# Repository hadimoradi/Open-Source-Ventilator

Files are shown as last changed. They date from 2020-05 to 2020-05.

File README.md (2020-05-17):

# Automated Ambubag
Auto Ambubag is a device to provide the minimum requirement for the patient in the critical situation facing COVID-19.

Auto Ambubag is suitable for various sizes of  Ambu bag. It scans the scale at the start time.

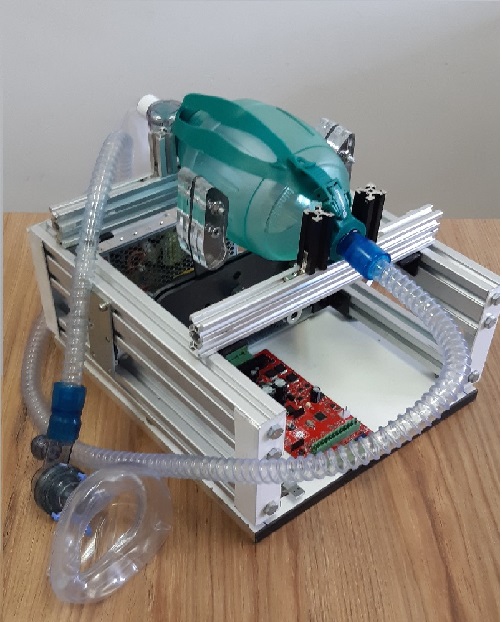
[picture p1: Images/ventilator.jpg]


### Breathing Parameters 
- #### Respiration Rate: 
     8-30 Respiration per minute 
- #### Tidal Volume:
  200-1000 cc per Ambu pumped
- #### I/E Rate(Inhale/Exhale Rate):
  1:1 , 1:2 , 1:3 , 1:4
- #### T hold:
  Ambu compressing time 

### Electrical Details
- voltage: 220 AC
- power: 200 W 

### Dimnetions 

32 * 36 *30 cm

10 kg

### TODO List
-  backup battery 
- measuring pick pressure, plateau,PEEP
- external oxygen cylinder

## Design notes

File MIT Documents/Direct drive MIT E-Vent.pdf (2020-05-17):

3/28/20 6:40 PM | 1

Gearmotor & “Windshield wiper” motors as direct drive units for MIT-E Vent: “TwinDrive” March 28, 2020, updated 3/30/2020
Prof. Alex Slocum, slocum@mit.edu
https://e-vent.mit.edu/

Background

On March 12, 2020 I started the quest for design, build, test an emergency breathing assist device in response to the critical shortage of ventilators the COVID-19 pandemic has created. My lab members volunteered to help and we formed the MIT-E Vent team (https://e-vent.mit.edu/ where we post information to share with the world) and we learned rapidly and made a lot of progress. Hindsight is often 2020, and this being 2020. The full story is part of another document… the purpose of this document is to describe how a geared mechanism led to a direct drive mechanism.

In general, rotary motion is preferred over sliding because it is more robust for millions of cycles in an environment that cannot be relied upon to carefully maintain the unit. Hence two hands pivoting together to squeeze an “Ambu bag” is a natural design to pursue. The force required on a pivoting “hand” at the Ambu bag center is about 100N to generate 50 cm H2O pressure. The distance from the pivot to center axis of a 125 mm (5 inch) diameter bag to get good “squeeze” is about 125-150mm. The speed of the bag center for compression to meet inspiration is thus about 176 mm/sec (7 in/s). FIRST robotics uses gearmotors with integral encoders and indeed an AndyMark PG71 motor we had on-hand proved to be very useful to develop the design concept of using a single motor to drive two pivoting hands geared together. However, millions of units worldwide will be needed, and in the search for a strong gearmotor to pivot the two hands geared together, it was suggested by many people contacted for their thoughts on the design to make it work with windshield wiper motors: Indeed a former student and business partner on ventures past, Dave Gessel who lives in Iraq, emailed me “There aren't any new "parts" here other than spares for things like cars or maybe washing machines. Car seat or windshield wiper motors, smart phone control, fabrication with hand tools OR import complete.” But windshield wiper motors typically have 10-15 N-m of stall torque, not enough to power two hands…

Meanwhile, a whole series of emails between the MIT E-Vent team and Toyota indicated that their wiper motors could match the specs of the AndyMark gearmotors, and an encoder could then be attached to one of the shafts that holds the hands. I had been discussing different drive methods for “paddle hands” with Richard Moore from Ford who was pursuing a system actuated by a geartrain powered by a standard motor Ford uses in its products. Richard was kind enough to check on windshield wiper gearmotor information (we still need to know what the allowable side load is on the output shaft)…

In addition, a few days ago my friend (and alum form my lab at MIT) Dr. Matthew Van Doren, who I had asked to help with stepper motor control for the TopDrive system created in concert Marcel Botha from NewLab.com. Steve Cohen and Marcel started NewLab as a way to help start a design and manufacturing renascence in NYC. Marcel and his amazing team of design people in New York in a matter of only a day took my early solid model for a “Top Drive” and evolved, built, and delivered test units for controls development.

Matt was working on the controls for the TopDrive unit provided to him by NewLab, and it got him thinking that modular robotic actuators (HDT A24 Actuator) that his brother’s robotics firm developed could directly power the fingers (or hands) that squeeze the Ambu bag. Matt took the shape of the rolling contact hands from the TopDrive and created a direct drive image or a very simple and modular system core:

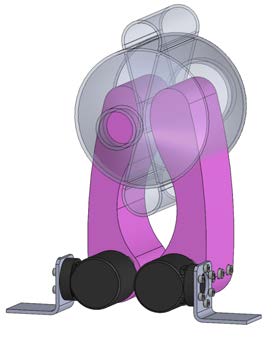
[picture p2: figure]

The HDT actuators are self-contained with controller, encoder…. really nice units. Perhaps more expensive than a couple of windshield wiper motors on a bracket with a simple control system, but hundreds a month can be in production right away, and they are a proven hardened and high-performance product, and HDT is an approved FDA manufacturer of such hardware.

Shortly thereafter, Richard Moore sent me this image of a Ford windshield wiper motor spec sheet, which is 2-3x stronger than what I have been used to in earlier hobby projects, and the higher torques now available inspired me to think fresh:

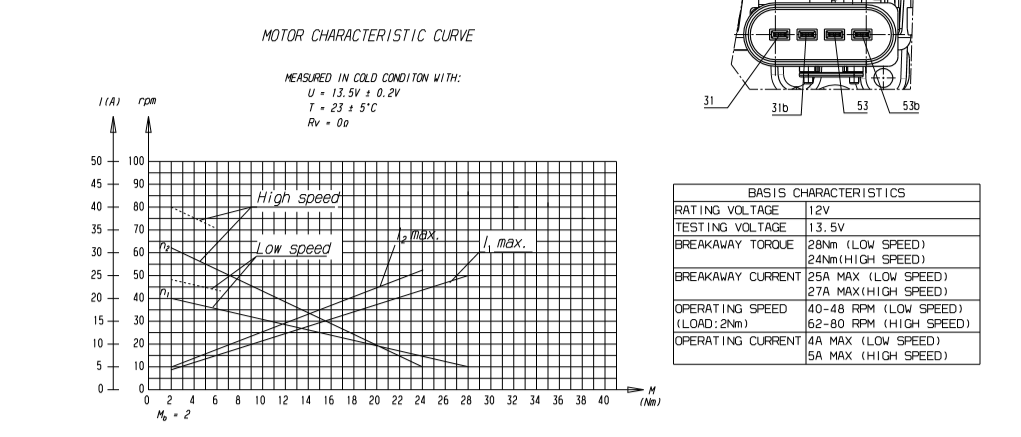
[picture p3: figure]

Déjà vu? Below is the image from my book FUNdaMENTALS of design that I wrote for course 2.007 where 25 years ago we were providing students big windshield wiper motors (note image in upper right of page) to use in their kits which had been donated by Ford! I still have a drawer of them in my basement:

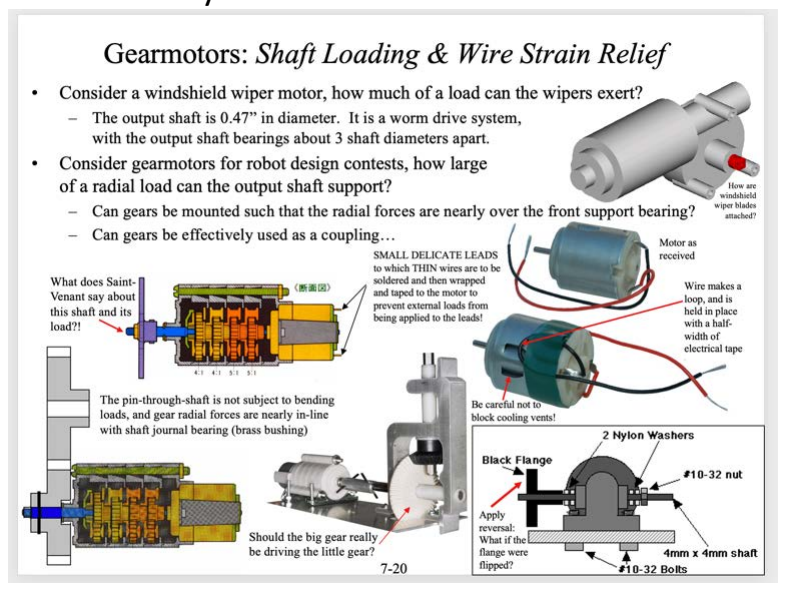
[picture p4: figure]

I had to put all this together, so I took a dog walk Saturday afternoon through our 100 acre woods, thinking about all the calculations I had been doing in spreadsheets for the geared hand
designs, and the dimensions and forces | POW it hit me while doing a first order analysis on
the trail…. The windshield wiper motors themselves might along work as a direct drive actuator. I came home and sketched the idea and then went to work modifying y design spreadsheet for the geared hands design while Solid Modeling the concept driven by the primary functional requirements of “hands” attached directly to output shaft of gearmotors (minimize complexity), minimize rubbing of the bag and motion of bag centerline while achieving a tidal volume flow of > 800 cm^3, and of course safety and fail safe operation ability.

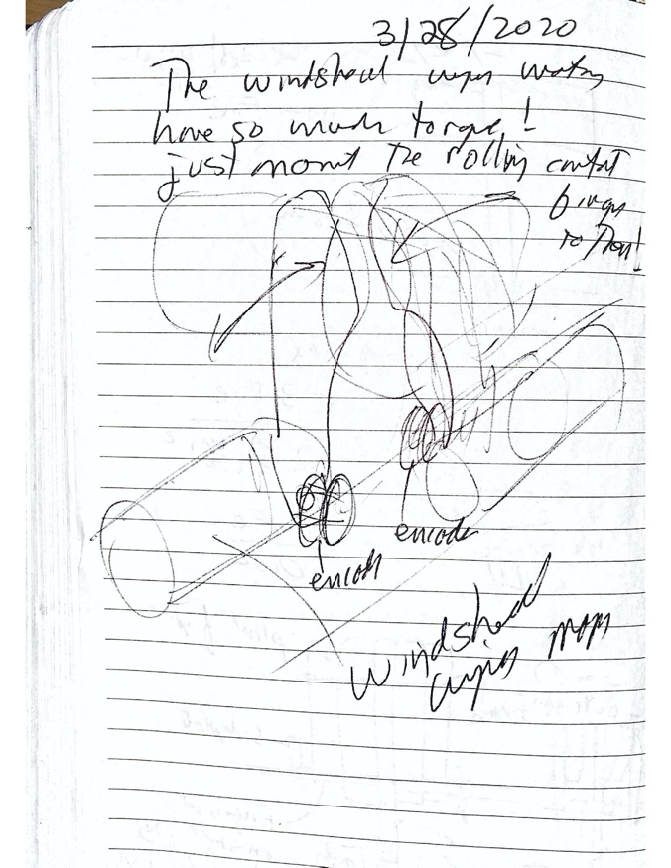
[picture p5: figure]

Had someone suggested this before in the past few days? I do not recall as these past days has been such a whirlwind as every day we hear how things are getting worse… so many lives at stake…. Thus, the thought was we could attach an “arm” to a windshield wiper motor output shaft, where the arm has “fingers” on each side like the MIT-E Vent unit we developed to create a wide “hand” to hold and compress the bag:

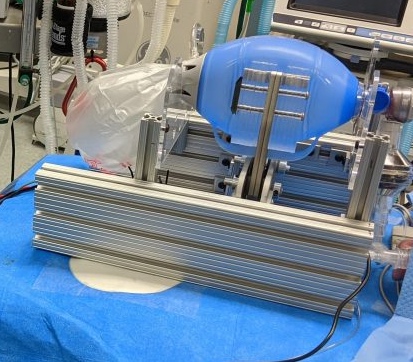
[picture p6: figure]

The key is the shape that squeezes the bag nicely as these early images from development of the TopDrive design report of 3/21/2020 show:

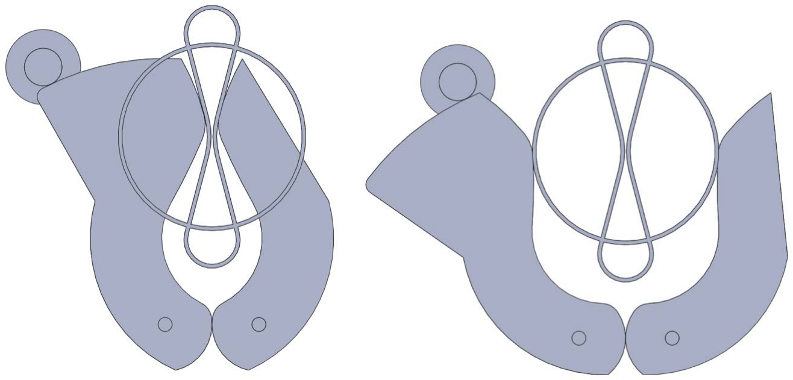
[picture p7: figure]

More than just effective rolling contact, then hands need to press on a wide surface region of the bag from both sides to get the “two hands” volme potential of the bag (>800 cc’s tidal volume of air).

“TwinDrive” concept

The key to direct drive the hands that squeeze the bag is a gearmotor to whose output shaft can be directly affixed an ”arm” with a “hand” that pushes on the bag. To minimize the torque required is to reduce the distance from the center of the bag to the rotation axis; however, the further away the hand is from the gearmotor axis of rotation, the more linear and uniform the motion of bag squeezing. The challenege then is to create a “cam-like” shape that is nice to the bag (minimize rubbing and motion of bag centerline). The original design was evolved with a few long contemplative walks through the woods to yield a reduction from the original 5.5” to 4.5” which results in 18% reduction in torque. The profile was also evovled to squeeze more of the bag giving more potential tidal volume:

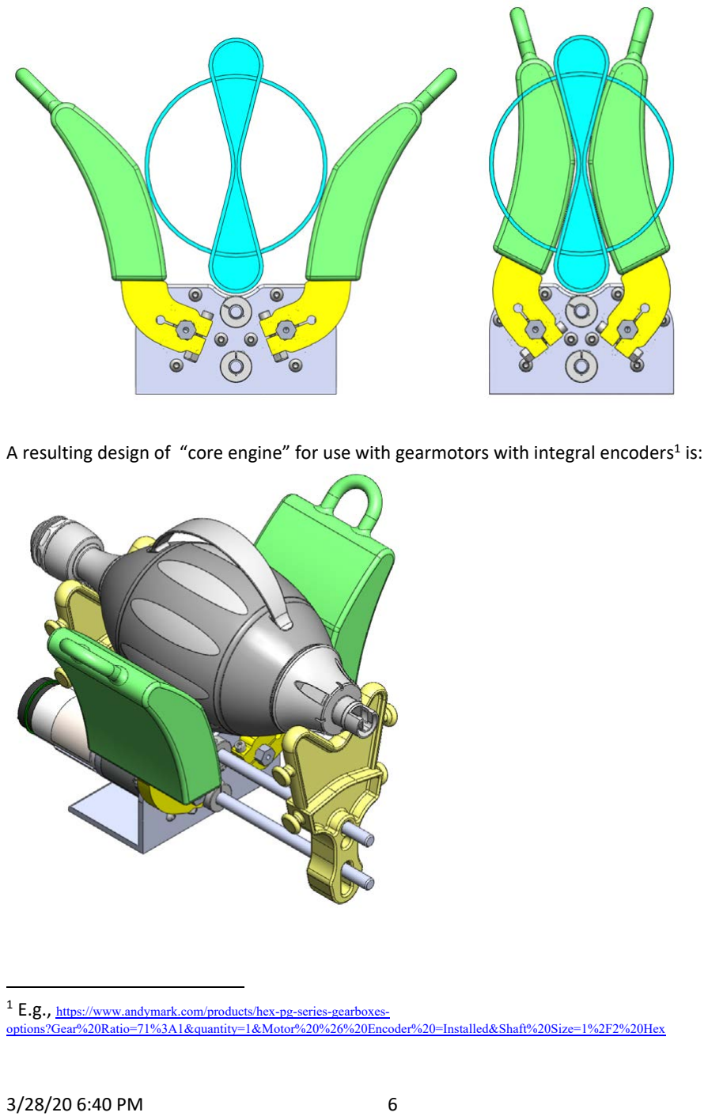
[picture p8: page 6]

A resulting design of “core engine” for use with gearmotors with integral encoders¹ is:

1 E.g., https://www.andymark.com/products/hex-pg-series-gearboxes-options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

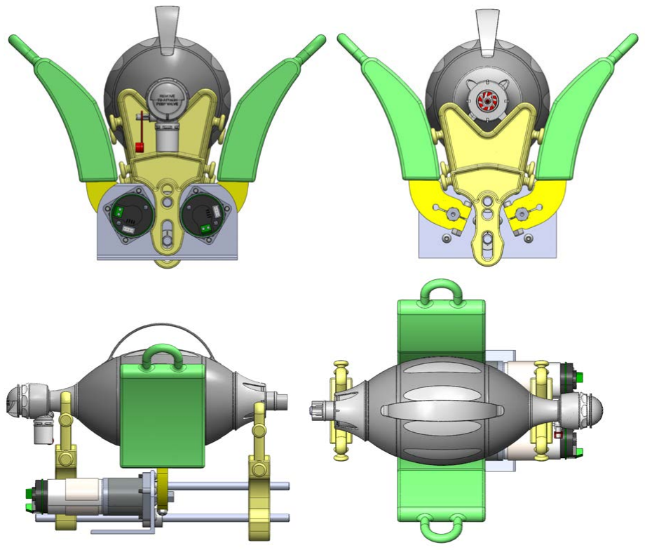
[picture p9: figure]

One can envision how the core design can be easily adpated for use with diffferent gearmotors or windshield wiper motors which can be mounted on opposing faces of a deep channel.

Position Sensing

Gearmotors with encoders provide very good feedback, but they will still need a home position flag. Windshield wiper motors generaly do not have inetrgal position sensors, but if they did (for dorect drive of wier blades) that would be a huge binus.

Else it would be very straightforward to on the arm have an arc shape on the bottom surface with fine “teeth” that an inductive sensor “count” (two can be used to yield quadrature effect)…. The design concept is very straightforward and the accompanying design spreadsheet can help bright engineers and makers all over the world rapidly design and make breating assist devices, whch are cntrolled by systems created by their electrical engineering counterparts, all working othegtehr with medical doctors to help people.

Fail-Safe Design

Some gearmotors with very high ratios or with wormgears are not backdriveable, as is common with many windshield wiper motors. This presents a hazerd of the bag is squeezed and the motor fails, because a clinician could not simply pry open the hands and pull the bag out. The answer is to pull the bag and hands out: this is made possible by creating a smooth curve over which printed hands slide:

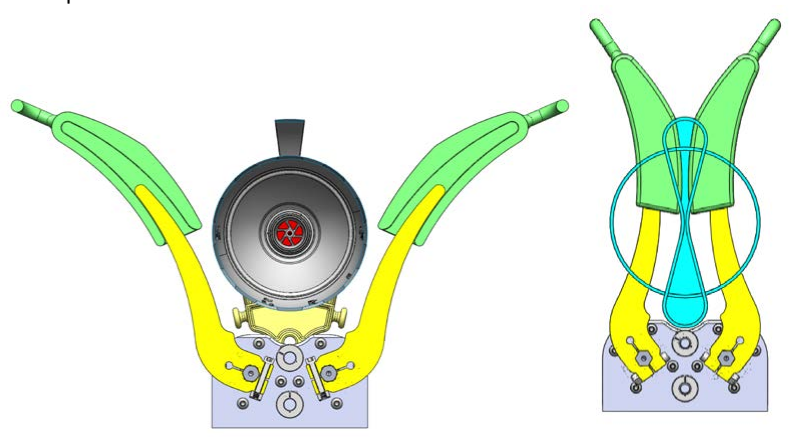
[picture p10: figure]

“Hands” on 3D printing

3D printing cn be most helpful to prodce the bag fixturing devices (although they can later be injection molded). The “hands” (green) can be mlded with a rotating core, but for now can be 3D printed. They have generous sections, but FEA stress analysis should be done as well as testing because many 3D printing processes produce nice parts but can be mdest strength, and these “hands” need to last for at least one million cycles (ideally 10 million). It isanticipated that creative people will evolve the hands to optimize their strength and minimize materials used while maintaining the bag-contact and emegerncy pull off surfaces.

Overall package

The above represents the “core engine”, where the solid model elements and design spreadsheet will be posted on https://e-vent.mit.edu/. However, it still needs the overall package (can it be run “open” as shown or is some shielding needed? Should it come with a stand? Where does the power electronics and controller and display screen go? … Many details to be done, but this could be done rapidly by skilled product design team, and units could be up and running in less than a week.

Path Forward

1) Maintain full speed ahead on producing the very robust “Top Drive” system being brought forward by NewLab should continue forward full speed as it is ready to go into production as soon as pig trials are completed Monday 3/30/2020.
2) Start rapid deveopment of the DirectDrive system:
a. Standardize the “arm” and hand designs (or at least te upper curved part of the arm and the hands): ideally the hands should be designed to be molded.
b. Launch the “high end” direct drive version which is the HDT A24 Actuator based system, which would readily achieve FDA approval as it was developed under a DARPA grant for medical applications as I recall. Dr. Alex Slocum Jr. (MD) and Dr. Albert Kwon have been working on FDA documents for the current gear driven finger designs we have been developing and they could thus work with Dr. Van Doren to move this rapidly forward.
c. Bring forth the direct drive version with off-the-shelf gearmotors with integral encoders. A generic control system is needed.
d. Automotive industry and its supply chain quickly configure a windshield wiper motor direct drive version, position sensing can be achieved with the inductor sensor looking at ridges on the “arm” as it rotates.
e. In all of the above, there is some risk in can for example windshield wiper units really withstand operating continually for 6 months? They might need a fan to cool the motors but that should not be an issue and they would be very inexpensive… the MIT team did this with the AndyMark motors successfully.

Note someone might ask “why did you not think of direct drive first?” Well, the above is recounting the process we have done and in the end the development of the hand shape the controls, the pig tests…. All going forward we likely would not be much faster, and spent maybe a bit less money and have fewer frayed nerves, but in the end wat natters is get emergency breathing assist devices to hospitals ASAP

The spreadsheet calculations for the windshield wiper motor-based system are shown below so they are all in this one document:

MIT-E VENT Direct Drive System Design spreadsheet

Spreadsheet to investigate ambu bag squeezer using "hands" directly mounted to wobust windshield wiper motors created by Prof. Alex Slocum March 28, 2020, see "Revisions" tab
Inputs in BLACK, Outputs in RED

Bag and Hand
Bag diameter | Dbag | 125 | mm
| | 5 inches
Bag length effectively compressed | Lbag | 125 | mm
Percent bag diameter compressed for full tidal volume | pbdc | 90%
Distance "hand" moves towards center of bag | disphand | 56 | mm
distance plane of center of bag to center of hand rotation | R_1 | 114.3 | mm
| | 4.5 inch
arc of travel of hand to compress bag | arcfing | 28 | degrees
Respiration
Peak for shorter periods | resprate | 40 | breaths per minute
Average for mechanism life and motor power calculations | resprateavg | 30 | breaths per minute
seconds per breath | spb | 2.00
Inspiratory/expiratory ratio | ier | 1:4
Inspiration ratio | insp | 1 | portion of cycle
Expiration ratio | expr | 4 | portion of cycle
Total parts | tpb | 5 | total portions
Time to inhale | tinsp | 0.40 | seconds
Time to exhale | texh | 1.60 | seconds
Portion of inhalation to ramp | pcr | 0.1 | percentage
time to ramp to pressure and ramp down | trtp | 0.04 | seconds
Percent of inhale time for ramp up and ramp down | xpramp | 10%
average linear speed of hand at bag center | vhandc | 176 | mm/sec
average rpm of finger | rpmfing | 14.69 | rpm
Forces on "Hands" from airway pressure in bag
peak airway pressure | pap | 40 | mmHg
| | 52 cmH2O
factor higher to force from bag through circuit | papeta | 0.9
bag pressure | pbagmm | 44.4 | mmHg
| | 0.058 atm
| | 0.860 psi
| | 0.006 N/mm^2
| cmH2O | 57.8 | cmH2O
| Areabag | 15625 | mm^2
Radial force on bag from each hand | Fbag | 92.6 | N
| | 20.8 lbs

Estimated Motor Size Required for the System
Life cycle
Breaths per day | bpdavg | 43,200
Days of life of machine before rebuild | dolm | 180
Total machine cycles required | tmcd | 7,776,000 | cycles
Motor Power estimate to start design
Radial velocity of bag sides during inhalation | Vrbagsides | 156.3 | mm/sec
Power applied to compress bag during inhalation portion of breathing cycle | Pbaginhale | 29.0 | Watts
mechanical system effieicny (gearmotor and connection to bag mechanism) | etamech | 0.8
Oversize motor for 100% duty cycle | ovszf | 150%
Estimated total peak motor mechanical power to select candidate motors | Pmotorest | 54 | Watts

Direct Drive Design: One windshield wiper motor per hand
Force on a each "hand" as bag is compressed | Ffinger | 92.6 | N
gearbox output torque needed | Tgm | 10,590 | N-mm
| | 94 lb-in
Motor Selection and operating parameters
N motor size (Nema 23, 34 or Gearmotor 1, 2, 3 see workbook "Motor Options")Nmsize | | 3
Stall torque | Tstallsm | 28.0 | N-m
| Tstallsmm | 28,000 | N-mm
Free speed | wfree34 | 70 | rpm
max radial force 20mm from face | Fradmaxm | 200 | N
required speed for respiration cycle | rsarc | 15 | rpm
torque available at required speed | NemaTas | 22,126 | N-mm
torque required for desired performance | tgm | 10,590 | N-mm
| | 94 lb-in
Summary
Airway pressure provided (as requested) | pap | 52 | cmH2O
Airway pressure possible if all torque aailable at speed is used | papmax | 109 | cmH2O
Peak Inspiratory Pressure valve threshold | | 75 | cmH2O

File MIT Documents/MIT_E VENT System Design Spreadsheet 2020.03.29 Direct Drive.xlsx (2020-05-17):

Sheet: System Analysis
MIT-E VENT Direct Drive System Design spreadsheet
Spreadsheet to investigate ambu bag squeezer using "hands" directly mounted to wobust windshield wiper motors
created by Prof. Alex Slocum March 28, 2020, see "Revisions" tab
Inputs in BLACK, Outputs in RED
Bag and Hand |  |  |  | Comments
Bag diameter | Dbag | 125 | mm
 |  | 5 | inches
Bag length effectively compressed | Lbag | 125 | mm | Longer than just the hand wdth, as ends dragged in
Percent bag diameter compressed for full tidal volume | pbdc | 90%
Distance "hand" moves towards center of bag | disphand | 56.25 | mm
distance plane of center of bag to center of hand rotation | R_1 | 114.3 | mm
 |  | 4.5 | inch
arc of travel of hand to compress bag | arcfing | 28.19674189 | degrees
Respiration
Peak for shorter periods | resprate | 40 | breaths per minute
Average for mechanism life and motor power calculations | resprateavg | 30 | breaths per minute
seconds per breath | spb | 2.00
Inspiratory/expiratory ratio | ier | 1:4
Inspiration ratio | insp | 1 | portion of cycle
Expiration ratio | expr | 4 | portion of cycle
Total parts | tpb | 5 | total portions
Time to inhale | tinsp | 0.40 | seconds
Time to exhale | texh | 1.60 | seconds
Portion of inhalation to ramp | pcr | 0.1 | percentage
time to ramp to pressure and ramp down | trtp | 0.04 | seconds | NOTE if during the inhale time tinhale (e.g. 0.4 seconds total) if assume x% for ramp up and x% for ramp down , then over total travel of Y degrees, the motor speed required (upper limit) is Y/(tinhale*(1-2x))
Percent of inhale time for ramp up and ramp down | xpramp | 10%
average linear speed of hand at bag center | vhandc | 175.78125 | mm/sec
average rpm of finger | rpmfing | 14.69 | rpm
Forces on "Hands" from airway pressure in bag
peak airway pressure | pap | 40 | mmHg
 |  | 52 | cmH2O
factor higher to force from bag through circuit | papeta | 0.9
bag pressure | pbagmm | 44.4 | mmHg
 |  | 0.058 | atm
 |  | 0.860 | psi
 |  | 0.006 | N/mm^2
 | cmH2O | 57.8 | cmH2O
 | Areabag | 15625 | mm^2 | force on EACH finger
Radial force on bag from each hand | Fbag | 92.6 | N
 |  | 20.8 | lbs
Estimated Motor Size Required for the System
Life cycle
Breaths per day | bpdavg | 43200
Days of life of machine before rebuild | dolm | 180
Total machine cycles required | tmcd | 7776000 | cycles | : =Dbag/2/tinsp
Motor Power estimate to start design |  |  |  | : =2*Fbag*Vrbagsides/1000. NOTE the factor of 2 is because one motor drives both fingers
Radial velocity of bag sides during inhalation | Vrbagsides | 156.2 | mm/sec
Power applied to compress bag during inhalation portion of breathing cycle | Pbaginhale | 29.0 | Watts
mechanical system effieicny (gearmotor and connection to bag mechanism) | etamech | 0.8
Oversize motor for 100% duty cycle | ovszf | 150%
Estimated total peak motor mechanical power to select candidate motors | Pmotorest | 54.28565994 | Watts |  |  | 2
 |  |  |  |  |  | #REF!
Direct Drive Design: One windshield wiper motor per hand
Force on a each "hand" as bag is compressed | Ffinger | 92.6 | N
gearbox output torque needed | Tgm | 10589.61226 | N-mm
 |  | 93.68850975 | lb-in
Motor Selection and operating parameters |  |  |  |  | Motor Data from "Motor Options" workbook
N motor size (Nema 23, 34 or Gearmotor 1, 2, 3 see workbook "Motor Options") | Nmsize | 3 |  | "3" is strong windshield wiper motor | Motor number | 23 | 34 | 1 | 2 | 3
Stall torque | Tstallsm | 28.0 | N-m | : =IF(NMsize=23,G88,IF(NMsize=34,H88,IF(NMsize=1,I88,IF(NMsize=2,J88,K88)))) | Stall torque (N-m) | 1.801415625 | 4.2 | 22.51562103 | 15.60 | 28.00
 | Tstallsmm | 28000 | N-mm | : =IF(NMsize=23,G88,IF(NMsize=34,H88,IF(NMsize=1,I88,IF(NMsize=2,J88,K88))))
Free speed | wfree34 | 70 | rpm |  | no load speed (rpm) | 900.00 | 720 | 75 | 59 | 70
max radial force 20mm from face | Fradmaxm | 200 | N |  | allowable side load (N) | 75 | 220 | 89 | 89 | 200
required speed for respiration cycle | rsarc | 14.68580307 | rpm
torque available at required speed | NemaTas | 22125.67877 | N-mm
torque required for desired performance | tgm | 10589.61226 | N-mm
 |  | 93.68850975 | lb-in
Summary
Airway pressure provided (as requested) | pap | 52 | cmH2O
Airway pressure possible if all torque aailable at speed is used | papmax | 108.6475376 | cmH2O
Peak Inspiratory Pressure valve threshold |  | 75 | cmH2O

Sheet: Arm stress
Force applied | Fapply | 20.8 | lb
Arm thickness | tarm | 0.5 | in
Arm width at root of slide-over | warm | 0.87 | in
Moment arm length | Lma | 3 | in
Moment of inertia/distance to neutral axis | I | 0.063075
Bending stress | sigbend | 990.2339516
Material |  | mild steel or aluminum
Max bending stress | sigmax | 35000 | psi
Stress concentration at root | scf | 2
Resulting afety factor | dsf | 17.7

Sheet: Motor Options
 | Enter numbers in BLACK, equivelants are calculated in RED, and then these values are transferred to the "System Analysis" spreadsheet
Motor number referenced on "System Analysis" sheet
1 | AndyMark PG71 gearmotor. https://www.andymark.com/products/hex-pg-series-gearboxes-options
 | Stall torque | Tstall | 16.6 | lb-ft | 22.52 | N-m
 | Free speed | wfree | 75 | rpm | 1.31 | rad/sec
 | estimated allowable side load on shaft | ? No spec found, so estimate | 20 | lb | 89 | N
 | est peak power (1/2 stall torque X 1/2 free speed) |  |  |  | 7.4 | W
2 | "Windsheild wiper motor" e.g., http://schmittongaromarine.com/site/1922schm/Technical_Specifications_for_Heavy_Duty_Wiper_Motors_309,319,_and_329_series.pdf. https://www.oslv.com/Products/Gearmotor-for-windshield-wipers-MRT62-43/98-25-1-en.html
 | Stall torque | Tstall | 11.5 | lb-ft | 15.60 | N-m
 | Free speed | wfree | 59 | rpm | 1.03 | rad/sec
 | estimated allowable side load on shaft | ? No spec found, so estimate | 20 | lb | 89 | N
 | est peak power (1/2 stall torque X 1/2 free speed) |  |  |  | 4.0 | W
3 | Fprd windshield wiper motor
 | Stall torque | Tstall | 20.6 | lb-ft | 28.00 | N-m
 | Free speed | wfree | 70 | rpm | 1.22 | rad/sec
 | estimated allowable side load on shaft | ? No spec found, so estimate | 44.94382022 | lb | 200 | N
 | est peak power (1/2 stall torque X 1/2 free speed) |  |  |  | 8.6 | W
23 | Nema 23 Stepper motor
 | Stall torque | Tstall | 255 | oz-in | 1.801415625 | N-mm
 | Free speed | wfree | 900 | rpm | 15.71 | rad/sec
 | estimated allowable side load on shaft |  | 16.85393258 | lb | 75 | N
 | est peak power (1/2 stall torque X 1/2 free speed) |  |  |  | 7.1 | W
34 | Nema 34 Stepper motor
 | Stall torque | Tstall | 595 | oz-in | 4.2 | N-m
 | Free speed | wfree | 720 | rpm | 12.57 | rad/sec
 | estimated allowable side load on shaft |  | 49.43820225 | lb | 220 | N
 | est peak power (1/2 stall torque X 1/2 free speed) |  |  |  | 13.2 | W
 | https://szbobet.en.alibaba.com/product/60516551996-803622807/BM_Brand_High_precision_4_Axis_8_5Nm_1204oz_in_Nema_34_Stepper_Motor_with_braker_Driver_Kit_For_C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
 | https://hardware-cnc.nl/en/shop/stappenmotoren/stepper-motor-34/stepper-motor-nema-34-4,5nm-detail
 | NEMA 23
 | https://cnc1.lv/en/stepper-motors/48-nema-23-stepper-motor-23hs9430-with-280-nm.html

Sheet: Hex drive
 |  | Metal torque arm
hex shaft diameter | hsd | 0.500 | in
 |  | 12.7 | mm
Width of contact face | wcf | 0.75 | in
 |  | 19.05 | mm
torque to be transmitted | ttbt | 93.68850975 | lb-in
constant from the torque integral | Chexpres | 0.064
Number of hex faces assumed to transmit the torque | Nhftt | 3
contact pressure on hex faces | hcpf | 10415.01626 | psi
 |  | 71.84 | MPa
NOTE 1/2" hex yields plastic contact pressure of 8,649 psi which is ok for Nylon 6-6 30% glass filled but tie in with steel driver for security

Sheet: lung compliance notes
Lung Compliance Update; Alexander Slocum, Jr, MD PhD; on 3/22/2020; sent to Albert Kwon and Christoph Nabzdyk 3/22/2020
 |  |  |  |  | Clinical scenario: 300-400 lb patient who has a lung compliance of 3? Also patient is bucking, having difficulty breathing.
Normal lung compliance, lower bound | LCNL | 50 | cmH2O
Normal lung compliance, upper bound | LCNU | 100 | cmH2O
 |  |  |  | Change from lower bound
Bad compliance, ARDS | LCA | 3 | cmH2O | 16.7
Resp rate lower bound |  | 8 | breaths
Resp rate upper bound |  | 40 | breaths
PEEP | PEEP | 15 | cmH2O | This exists everywhere in the breathing curcuit AFTER the valve; so inspiratory pressure of 30 is between bag & valve
Inspiratory pressure | Pins | 30 | cmH2O
Driving pressure (at machine) | Pmach | 15 | cmH2O
Driving pressure (at mouth) | Pmouth | 15 | cmH2O
Anticipated required airway pressure (need torque to generate this much press) | Preq | 30 | max

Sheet: refs
https://en.wikipedia.org/wiki/Mechanical_ventilation
https://www.sciencedirect.com/topics/medicine-and-dentistry/mean-airway-pressure
https://www.sciencedirect.com/topics/medicine-and-dentistry/airway-pressure

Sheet: Revisions
Version | date | who | edit
1 | 2020-03-28 | AHS Sr | used gear design based spreadsheet
2 | 2020-03-29 | AHS Sr | bending stress in arm and cleanup
 |  |  |  | 0.8181818182

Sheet: Bag fixture by Vee
Bag1eD | 50 | mm
Bag2eD | 40 | mm
Veeangle | 45 | degrees
deltaCenter | 3.54 | mm | distance center heigh shifts when supporting Bags of different end diameters in a Vee

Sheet: Expected Tidal Volume
cross section area of bag
before compression | 18.1 | 18.1 | in^2
after compression | 4.82 | 4.82 | in^2
length of compression zone | 3 | 4 | in^3
volume compressed | 39.84 | 53.12 | in^3
tidal volume | 653 | 870 | cm^3
% of ends also compressed | 20% | 20%
expected tital volume | 783 | 1045
actual measured by tests | >1000 cm^3

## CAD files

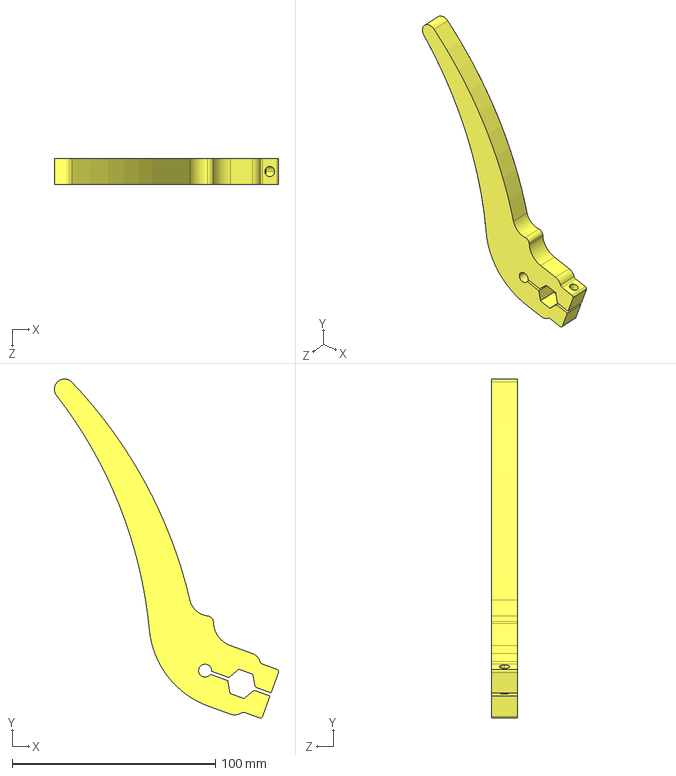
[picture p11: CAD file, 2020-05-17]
MIT Documents/arm.IGS
110.4 x 166.9 x 12.7 mm

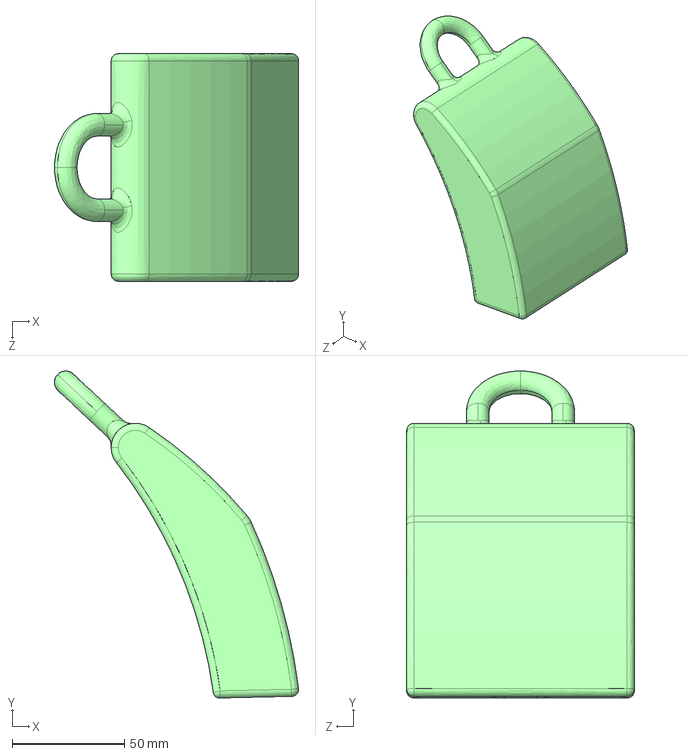
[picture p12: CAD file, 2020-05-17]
MIT Documents/hand.IGS
109.0 x 145.9 x 101.6 mm

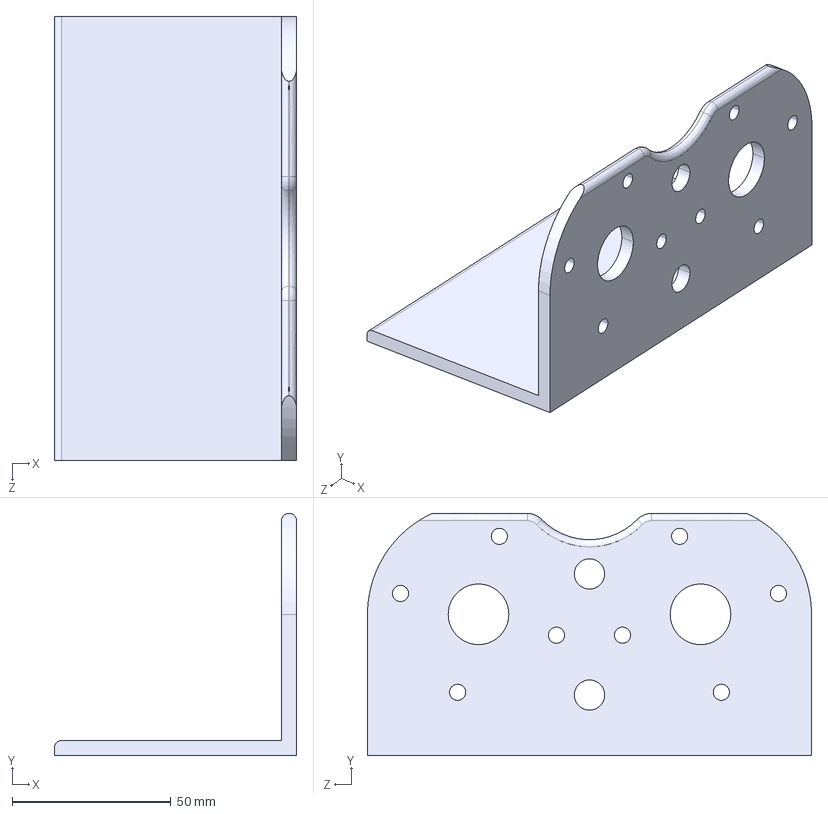
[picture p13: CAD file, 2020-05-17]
MIT Documents/AM motor mounting angle.IGS
76.2 x 76.2 x 139.7 mm

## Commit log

2020-05-17 upload MIT docs
    [AM motor mounting angle.IGS, MIT_E VENT System Design Spreadsheet 2020.03.29 Direct Drive.xlsx, arm.IGS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]
2020-05-17 upload image
    [MIT_E VENT Top Drive 2020.03.29 v9.xlsx]
